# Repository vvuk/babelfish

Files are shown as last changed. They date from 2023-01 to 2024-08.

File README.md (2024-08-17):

Babelfish
=========

_This is a work in progress._

Babelfish is a hardware device and associated software to allow using a USB keyboard and mouse on a variety of retro computers.

Planned or in progress emulations include:

* Apollo
  * DN[3-5]XXX, DN10000, HP9000 series 400 with Domain/OS.
  * DN300
* SGI (pre-PS2)
* Sun (pre-PS2)
* Mac ADB
* PS/2 ?

The Sun code is based on the (USB2Sun)[] project.

## Hardware

TBD.

## Building

TBD.

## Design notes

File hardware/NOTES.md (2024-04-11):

Babelfish
=========

# v0.3

Fixes from v0.2:
- CH_B_S0/S1 routed to GPIO12 and GPIO13
- exposed DB9 GPIO moved from GPIO13+14 to 14+15.
  - DB9 pin 4 became GPIO15, pin 5 became GPIO14

| GPIO # | Usage |
| ====== | ===== |
|  0 | TX_A |
|  1 | RX_A |
|  2 | CH_A_S0 - A channel output select |
|  3 | CH_A_S1 - A channel output select |
|  6 | LED_PWR |
|  8 | TX_B |
|  9 | RX_B |
| 10 | LED_P_OK |
| 11 | LED_AUX |
| 12 | CH_B_S0 |
| 13 | CH_B_S1 |
| 14 | GPIO14 |
| 15 | GPIO15 |
| 18 | USB2_D- |
| 19 | USB2_D+ |
| 20 | USB2_EN |
| 21 | USB2_FLG |
| 23 | STAT_5V0 |

# v0.2

TPMCP1703T-5002E/CB -- SOT-23-3 20V max input, 300mA max current. How will this play with 357mA current limit on TPS2113? And will this be enough to power USB and RP2040?
TPMCP1703T-3302E/CB - SOT-23-3 

DE9 connector. Female.

5   4   3   2   1
  9   8   7   6

1 - GND
2 - TX A
3 - TX B
4 - GPIO15
5 - GPIO14
6 - VCC_IN
7 - RX A
8 - RX B
9

# Legacy notes
## v01

debug connector:

3v3 SWCLK GND SWD

for power series, top pin is to feed lines

usb2
DP = GPIO19, pin 30
DM = GPIO18, pin 29

pin 1 - U0 TX  - GP0   A1
pin 2 - U0 RX - GP1   A2

pin 6 - U1 TX - GP4   A3
pin 7 - U1 RX - GP5   A4

U1 TX - GP8
U1 RX - GP9

U0 TX - GP12
U0 RX - GP13

U0 TX - GP16
U0 RX - GP17

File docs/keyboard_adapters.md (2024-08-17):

# Keyboard Adapters

Babelfish DE9 connector (Female):

```
5   4   3   2   1
  9   8   7   6

1 - GND
2 - TX A
3 - TX B
4 - GPIO14
5 - GPIO15
6 - VCC_5V (5V in, if available)
7 - RX A
8 - RX B
9 - 3v3 (out)
```

## Apollo

CPU end of _*cable*_ (yes, these are the actual DIN8 pin numbers):

```
              U          1 - +8.5 Vdc (see below)     Red wire
          6o    7o       2 - Data to CPU (TXD)        Yellow wire
                         3 - Logic ground             Green wire
        1o        3o     4 - RESET                    Orange wire
             8o          5 - Data to keyboard (RXD)   Grey wire
          4o    5o       6 - Not used
             2o          7 - Logic ground             Blue wire
                         8 - Not used
                    SHIELD - Chassis ground
```

| Babelfish DB9 | Apollo DIN8 |
| :--- | :--- |
| 1 (GND) | 3, 7 (Logic ground) (white/3) |  
| 2 (TX A) | 2 (Data to CPU) (light brown/light orange) |
| 7 (RX A) | 5 (Data to keyboard) (yellow) |
| | 4 (RESET) (dark brown) |

## Apollo DN300

RJ45 connector:

```
      | 1 2 3 4 5 6 7 8 |      1 - NC
      |                 |      2 - NC
      +---+         +---+      3 - +3V3 (maybe?)
          +-+     +-+          4 - Data to CPU (TXD)
            +-----+            5 - 1.2kHz clock
                               6 - Logic ground
                               7 - NC
                               8 - NC
```

| Babelfish DB9 | Apollo DN300 RJ45 |
| :--- | :--- |
| 1 (GND) | 6 (Logic ground) |
| 2 (TX A) | 4 (Data to CPU) |

## ADB

Looking at male cable end:

```
      3  4
     1    2
       == 

1 - yellow - DATA
2 - green - power sw
3 - red - VCC 5V
4 - black  - GND
```

| Babelfish DB9 | ADB Mini-DIN 4 |
| :--- | :--- |
| 1 (GND) | 4 (GND) (black) |
| 2 (TX A) | 1 (ADB) (yellow) |
| 3 (TX B) | 2 (Power SW) (green) |
| 6 (VCC_5V) | 3 (5V) (red) |

Cable I have has black, yellow, red, green. 

## Sun (pre-PS/2)

(todo)

## SGI (pre-PS/2)

(todo)

## NeXT

MCLK   7   yellow
MOUT   2   orange
MIN    3   green
-12v  nc
NC    nc
GND    1   brown

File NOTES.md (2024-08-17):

NeXT

0xc5 0xde 0x00 0x00 0x00 -- I think this is an address set? Should be 0xef?
0xc5 0x00 0x06 0x00 0x00 -- Hmm this should be 0x3, this is wrong?

many 0xff = reset

seen on MOUT:
0xc5 0x00 0x03 0x00 0x00 -- 0xC5 -- kbhi = 0x00, kblo = 0x03  -- turn both LEDs on
longish delay
0xc5 0x00 0x00 0x00 0x00  -- turn both LEDs off
delay
0xc6 0x01 0xff 0xff 0xf6 -- 0xc6 is supposed to be an asic-to-computer response?

kbhi = R2 R1 R0 RW x x x A0 ; 0x00 = register 0, write 0, data 0x3

Host 0xc5 0xf0 xx xx xx -- read keyb version, or 0xf1 read mouse version
Reply 0xc6 paddr asicrev devver devid

We should reply
  0xc6
  0b00010000 -- master keyboard, asic originated event
  0x00 -- old asic version
  msb -- metakey code
  lsb -- keycode

-- rom Monitor -- right command key + ~ key on numeric keypad

From Previous:

-> C5 EF000000  -> set addr to 0; should ignore
<- C6 70000000  -> is this some kind of ack?

-> C5 00030000  -> turn on left/right LEDs
<- C6 70000000

-> C5 00000000  -> turn off LEDs
<- C6 70000000

-> C6 01fffff6 -> ... uhh
-> 00
"Command read 0x00"

-> C6 01fffff6 -> Set keyboard mouse poll -- mask & speed, ahh
-> 00

Apollo

Keyboard log after booting domain_os:

```
[   50866] IN: 00 (bytes: 0 cmd: 00000000 reading_cmd: 0)
Unknown keyboard command start byte [not-in-cmd]: 00
[   57317] IN: ff (bytes: 0 cmd: 00000000 reading_cmd: 0)
[   57319] IN: 00 (bytes: 0 cmd: 00000000 reading_cmd: 1)
Keyboard command: 00000000
Got 00000000 command with 0 bytes
[   63278] IN: ff (bytes: 0 cmd: 00000000 reading_cmd: 0)
[   65254] IN: 00 (bytes: 0 cmd: 00000000 reading_cmd: 1)
Keyboard command: 00000000
Got 00000000 command with 0 bytes
[   65262] IN: ff (bytes: 0 cmd: 00000000 reading_cmd: 0)
[   65267] IN: 12 (bytes: 0 cmd: 00000000 reading_cmd: 1)
[   65272] IN: 21 (bytes: 1 cmd: 00000012 reading_cmd: 1)
```

i53 / 15 / 1637

ST15150N: 78 / 21 / 5119

after booting domain_os; responses resulted in junk answers to "do yo uawnt to run domain_os with current calendar" prompt:

(apollo:0) recv ff
(apollo:0) recv 00
(apollo:0)  command 00000000 (1 bytes)
(apollo:0) Setting keyboard mode to 0
(apollo:0) xmit ff
(apollo:0) xmit 00
(apollo:0)  command handled
(apollo:0) recv ff
(apollo:0) recv 00
(apollo:0)  command 00000000 (1 bytes)
(apollo:0) Setting keyboard mode to 0
(apollo:0) xmit ff
(apollo:0) xmit 00
(apollo:0)  command handled
(apollo:0) recv ff
(apollo:0) recv 00
(apollo:0)  command 00000000 (1 bytes)
(apollo:0) Setting keyboard mode to 0
(apollo:0) xmit ff
(apollo:0) xmit 00
(apollo:0)  command handled
(apollo:0) recv ff
(apollo:0) recv 12
(apollo:0)  command 00000012 (1 bytes)
(apollo:0) recv 21
[started sending here]

booting the os --

(apollo:0) recv ff
(apollo:0) recv 00
(apollo:0)  command 00000000 (1 bytes)
(apollo:0) Setting keyboard mode to 0
(apollo:0) xmit ff
(apollo:0) xmit 00
(apollo:0)  command handled
(apollo:0) recv ff
(apollo:0) recv 01
(apollo:0)  command 00000001 (1 bytes)
(apollo:0) Setting keyboard mode to 1
(apollo:0) xmit ff
(apollo:0) xmit 01
(apollo:0)  command handled
(apollo:0) recv ff
(apollo:0) recv 12
(apollo:0)  command 00000012 (1 bytes)
(apollo:0) recv 21
(apollo:0)  command 00001221 (2 bytes)
(apollo:0) keyboard ident request
'D-03863-MSxmit str '3-@
(apollo:0)  command handled
(apollo:0) recv 00
(apollo:0) recv 00
(apollo:0) recv 00
(apollo:0) recv 00
(apollo:0) recv 00
(apollo:0) recv 00
(apollo:0) recv 00
(apollo:0) recv 00
(apollo:0) recv 00
(apollo:0) recv 00
(apollo:0) recv 00
(apollo:0) recv 00
(apollo:0) recv 00
(apollo:0) recv 00
(apollo:0) recv 00

resulted in uqyqr\qru]puqk\ in the login prompt

upon using the mouse, the keyboard keys seem to be sending mouse input?

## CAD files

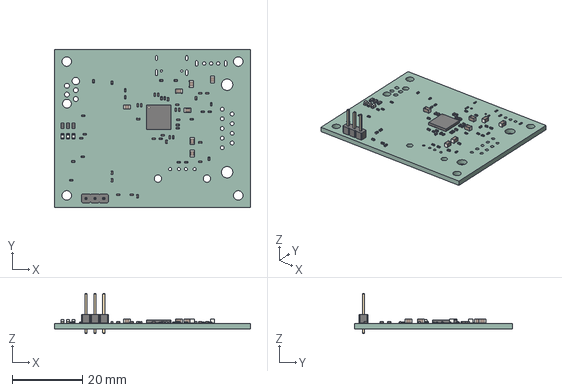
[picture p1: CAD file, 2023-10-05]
hardware/v2/babelfish.step
56.0 x 45.2 x 11.5 mm
babelfish PCB

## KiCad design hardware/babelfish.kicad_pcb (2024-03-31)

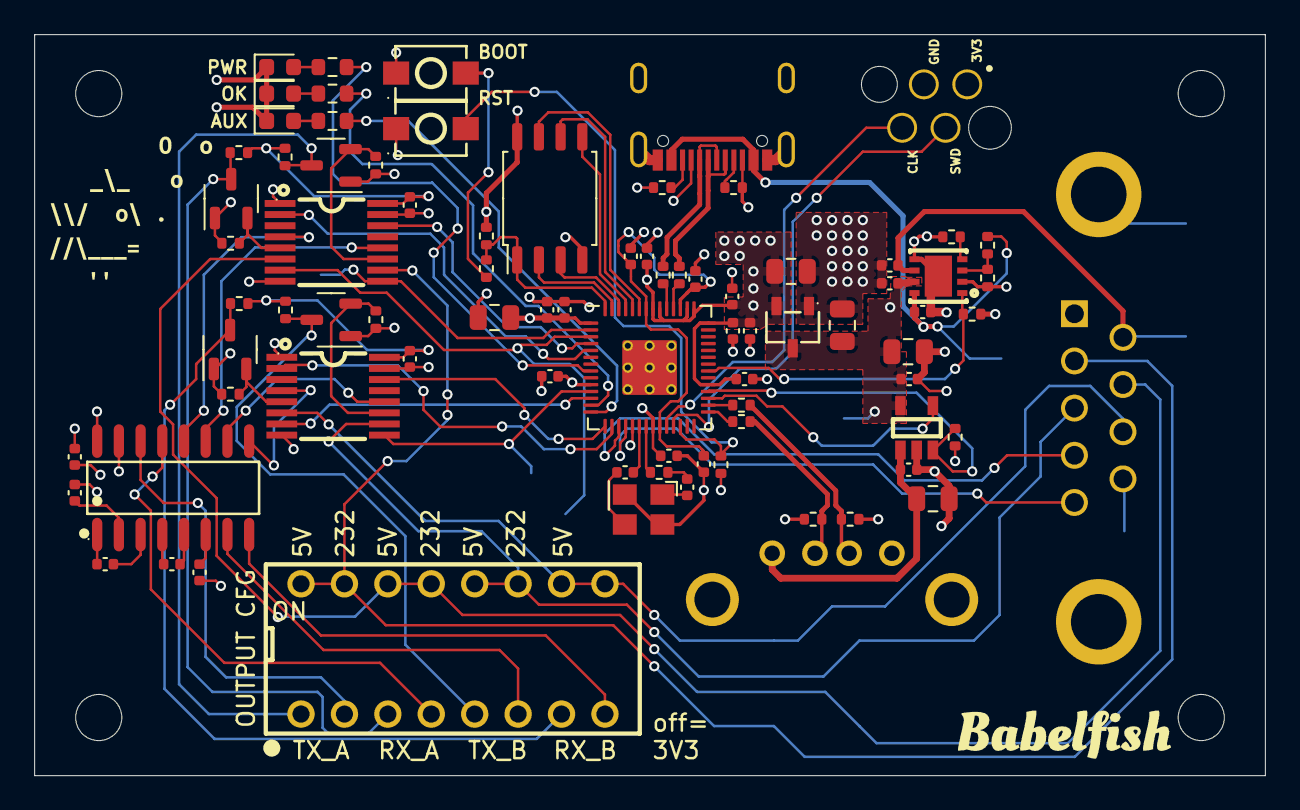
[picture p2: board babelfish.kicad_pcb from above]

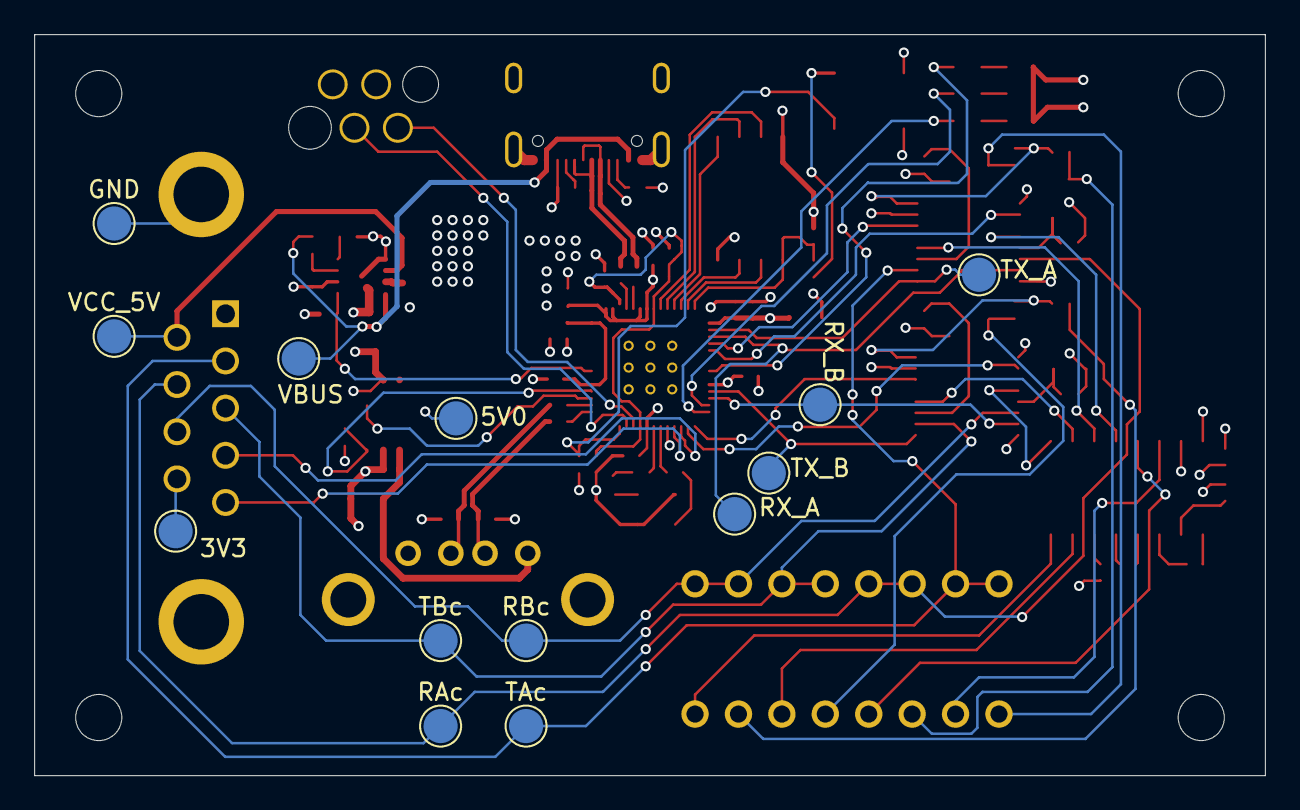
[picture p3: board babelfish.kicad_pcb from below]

Board: 4 copper layers, 72.0 x 43.4 mm, 101 parts (13 on the bottom side), 79 nets.

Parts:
3V3, 5V0: TestPoint; TestPoint_Pad_D2.0mm
C1, C2, C4, C5, C6, C7, C8, C9, C10, C15, C16, C18, C23, C24, C25, C26, C27, C28, C30, C36, C37: 100n; C_0402_1005Metric
C3, C21, C22, C29, C31: 10u; C_0805_2012Metric
C11, C12: 30p; C_0402_1005Metric
C13, C14, C17: 1u; C_0402_1005Metric
D1, D2, D3: Red; LED_0603_1608Metric
DIP1: KF1001-08P-R0-GL-DFT-01B; SW-TH_16P-L21.9-W9.9-P2.54-LS7.6
GND: TestPoint; TestPoint_Pad_D2.0mm
H1, H2, H3, H4: MountingHole; MountingHole_2.7mm_M2.5
J2: SWD; 490107670412
J3: DE9 Female; DSUB-TH_DMR-9S
J4: USB_A; USB-A-TH__USB-AF-90
Q1: BSS138; SOT-23-3
Q2, Q3, Q4: SOT-23-3
R1, R11: 1k; R_0402_1005Metric
R2, R14, R18, R19, R20, R21, R22, R23, R24, R25, R28: 10k; R_0402_1005Metric
R3, R4: 27; R_0402_1005Metric
R5, R10: 5.1K; R_0402_1005Metric
R6: 10k2; R_0402_1005Metric
R7: DNF; R_0402_1005Metric
R8: 2k05; R_0402_1005Metric
R9: 1k4; R_0402_1005Metric
R12, R13: 22; R_0402_1005Metric
R15, R16, R17: 1k; R_0603_1608Metric
R26, R27: 15k; R_0402_1005Metric
RAc: TestPoint; TestPoint_Pad_D2.0mm
RBc: TestPoint; TestPoint_Pad_D2.0mm
RX_A: TestPoint; TestPoint_Pad_D2.0mm
RX_B: TestPoint; TestPoint_Pad_D2.0mm
SW1, SW2: TS342A2P-WZ; SW-SMD_L4.0-W2.9-LS5.0
TAc: TestPoint; TestPoint_Pad_D2.0mm
TBc: TestPoint; TestPoint_Pad_D2.0mm
TX_A: TestPoint; TestPoint_Pad_D2.0mm
TX_B: TestPoint; TestPoint_Pad_D2.0mm
U1: RP2040; RP2040-QFN-56
U2: TPS2113ADRBR; SON-8_L3.0-W3.0-P0.65-LS3.0-BL-EP
U3: GT-USB-7010ASV; USB-C-SMD_G-SWITCH_GT-USB-7010ASV
U4: W25Q128JVS; SOIC-8_5.23x5.23mm_P1.27mm
U6: TPMCP1703T-3302E_CB; SOT-23-3_L2.9-W1.6-P1.90-LS2.8-BR
U7, U8: SN74CBT3253CPWR; TSSOP-16_L5.0-W4.4-P0.65-LS6.4-TL
U11: MAX3232IDR; SOIC-16_L9.9-W3.9-P1.27-LS6.0-BL
U12: AP2191WG-7; SOT-25-5_L2.9-W1.6-P0.95-LS2.8-BL
VBUS: TestPoint; TestPoint_Pad_D2.0mm
VCC_5V: TestPoint; TestPoint_Pad_D2.0mm
X1: X322512MSB4SI; OSC-SMD_4P-L3.2-W2.5-BL
kibuzzard-644F39EB: G***; kibuzzard-644F39EB
kibuzzard-644F3679: G***; kibuzzard-644F3679

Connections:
+1V1: C1.1, C2.1, C13.1, U1.23 (DVDD), U1.45 (VREG_VOUT), U1.50 (DVDD)
+3V3: 3V3.1, C3.1, C4.1, C5.1, C6.1, C7.1, C8.1, C9.1, C10.1, C14.1, C16.1, C22.1, C25.1, J2.1, J3.9, Q1.1 (G), Q2.1 (G), Q3.1 (G), Q4.1 (G), R2.2, R7.1, R14.2, R18.1, R20.1, R22.1, R24.1, R28.2, U1.1 (IOVDD), U1.10 (IOVDD), U1.22 (IOVDD), U1.33 (IOVDD), U1.42 (IOVDD), U1.43 (ADC_AVDD), U1.44 (VREG_IN), U1.48 (USB_VDD), U1.49 (IOVDD), U4.8 (VCC), U6.2 (VOUT), U11.16 (VCC)
/5V0: 5V0.1, C17.1, C21.1, C30.1, C31.1, C36.2, C37.2, R19.1, R21.1, R23.1, R25.1, U2.7 (OUT), U6.3 (VIN), U7.16 (VCC), U8.16 (VCC), U12.5 (IN)
/CH_A_S0: U1.4 (GPIO2), U7.14 (S0)
/CH_A_S1: U1.5 (GPIO3), U7.2 (S1)
/CH_B_S0: U1.15 (GPIO12), U8.14 (S0)
/CH_B_S1: U1.16 (GPIO13), U8.2 (S1)
/GPIO14: J3.4, U1.17 (GPIO14)
/GPIO15: J3.5, U1.18 (GPIO15)
/GPIO18: R12.2, U1.29 (GPIO18)
/GPIO19: R13.2, U1.30 (GPIO19)
/LED_AUX: R17.1, U1.14 (GPIO11)
/LED_PWR: R15.1, U1.8 (GPIO6)
/LED_P_OK: R16.1, U1.13 (GPIO10)
/OSC1: C11.1, X1.1 (OSC1)
/OSC1R: C11.2, R1.1
/OSC2: C12.1, X1.3 (OSC2)
/PWR_VSNS: R6.2, R8.1, U2.3 (VSNS)
/QSPI_SCLK: U1.52 (QSPI_SCLK), U4.6 (CLK)
/QSPI_SD0: U1.53 (QSPI_SD0), U4.5 (DI(IO0))
/QSPI_SD1: U1.55 (QSPI_SD1), U4.2 (DO(IO1))
/QSPI_SD2: U1.54 (QSPI_SD2), U4.3 (IO2)
/QSPI_SD3: U1.51 (QSPI_SD3), U4.7 (IO3)
/QSPI_SS: R7.2, R11.1, U1.56 (QSPI_SS), U4.1 (~CS)
/RUN: R14.1, SW2.2, U1.26 (RUN)
/RX_A: RX_A.1, U1.3 (GPIO1), U7.7 (1A)
/RX_A_CONN: DIP1.13 (PIN13), DIP1.14 (PIN14), J3.7, RAc.1, U7.6 (1B1)
/RX_A_MAX: U7.4 (1B3), U11.12 (ROUT1)
/RX_A_MAX_OUT: DIP1.4 (PIN4), U11.13 (RIN1)
/RX_A_SHIFTER: Q1.2 (S), R18.2, U7.5 (1B2)
/RX_A_SHIFTER_OUT: DIP1.3 (PIN3), Q1.3 (D), R19.2
/RX_B: RX_B.1, U1.12 (GPIO9), U8.7 (1A)
/RX_B_CONN: DIP1.9 (PIN9), DIP1.10 (PIN10), J3.8, RBc.1, U8.6 (1B1)
/RX_B_MAX: U8.4 (1B3), U11.9 (ROUT2)
/RX_B_MAX_OUT: DIP1.8 (PIN8), U11.8 (RIN2)
/RX_B_SHIFTER: Q4.2 (S), R24.2, U8.5 (1B2)
/RX_B_SHIFTER_OUT: DIP1.7 (PIN7), Q4.3 (D), R25.2
/STAT_5V0: R2.1, U1.35 (GPIO23), U2.1 (STAT)
/SWCLK: J2.4, U1.24 (SWCLK)
/SWD: J2.2, U1.25 (SWD)
/TX_A: TX_A.1, U1.2 (GPIO0), U7.9 (2A)
/TX_A_CONN: DIP1.15 (PIN15), DIP1.16 (PIN16), J3.2, TAc.1, U7.10 (2B1)
/TX_A_MAX: U7.12 (2B3), U11.11 (DIN1)
/TX_A_MAX_OUT: DIP1.2 (PIN2), U11.14 (DOUT1)
/TX_A_SHIFTER: Q2.2 (S), R20.2, U7.11 (2B2)
/TX_A_SHIFTER_OUT: DIP1.1 (PIN1), Q2.3 (D), R21.2
/TX_B: TX_B.1, U1.11 (GPIO8), U8.9 (2A)
/TX_B_CONN: DIP1.11 (PIN11), DIP1.12 (PIN12), J3.3, TBc.1, U8.10 (2B1)
/TX_B_MAX: U8.12 (2B3), U11.10 (DIN2)
/TX_B_MAX_OUT: DIP1.6 (PIN6), U11.7 (DOUT2)
/TX_B_SHIFTER: Q3.2 (S), R22.2, U8.11 (2B2)
/TX_B_SHIFTER_OUT: DIP1.5 (PIN5), Q3.3 (D), R23.2
/USB2_D+: J4.3 (D+), R13.1, R27.1
/USB2_D-: J4.2 (D-), R12.1, R26.1
/USB2_EN: U1.31 (GPIO20), U12.4 (EN)
/USB2_FLG: R28.1, U1.32 (GPIO21), U12.3 (FLG)
/USB_D+: R3.1, U3.A6 (DP1), U3.B6 (DP2)
/USB_D-: R4.1, U3.A7 (DN1), U3.B7 (DN2)
/USB_DN: R4.2, U1.46 (USB_DM)
/USB_DP: R3.2, U1.47 (USB_DP)
/VBUS_OUT: C28.1, C29.1, J4.1 (VBUS), U12.1 (OUT)
/VCC_5V: C18.1, J3.6, U2.6 (IN2), VCC_5V.1
/XIN: C12.2, U1.20 (XIN)
/XOUT: R1.2, U1.21 (XOUT)
/~USB_BOOT: R11.2, SW1.2
GND: C1.2, C2.2, C3.2, C4.2, C5.2, C6.2, C7.2, C8.2, C9.2, C10.2, C13.2, C14.2, C15.2, C16.2, C17.2, C18.2, C21.2, C22.2, C23.1, C25.2, C27.2, C28.2, C29.2, C30.2, C31.2, C36.1, C37.1, D1.1 (K), D2.1 (K), D3.1 (K), GND.1, J2.3, J3.1, J3.10 (PAD), J3.11 (PAD), J4.4 (GND), J4.5 (Shield), R5.2, R8.2, R9.2, R10.2, R26.2, R27.2, SW1.1, SW2.1, U1.19 (TESTEN), U1.57 (GND), U2.2 (EN#), U2.5 (GND), U2.9 (EP), U3.1 (SHELL), U3.2 (SHELL), U3.3 (SHELL), U3.4 (SHELL), U3.A1B12 (GND), U3.A8 (SBU1), U3.B1A12 (GND), U3.B8 (SBU2), U4.4 (GND), U6.1 (GND), U7.1 (1OE#), U7.8 (GND), U7.15 (2OE#), U8.1 (1OE#), U8.8 (GND), U8.15 (2OE#), U11.15 (GND), U12.2 (GND), X1.2 (GND), X1.4 (GND)
unnamed: D1.2 (A), R15.2
unnamed: D2.2 (A), R16.2
unnamed: D3.2 (A), R17.2
unnamed: R9.1, U2.4 (ILIM)
unnamed: R10.1, U3.A5 (CC1)
unnamed: R5.1, U3.B5 (CC2)
unnamed: C24.1, U11.1 (C1+)
unnamed: C24.2, U11.3 (C1-)
unnamed: C26.1, U11.4 (C2+)
unnamed: C26.2, U11.5 (C2-)
unnamed: C23.2, U11.2 (V+)
unnamed: C27.1, U11.6 (V-)
VBUS: C15.1, R6.1, U2.8 (IN1), U3.A4B9 (VBUS), U3.B4A9 (VBUS), VBUS.1

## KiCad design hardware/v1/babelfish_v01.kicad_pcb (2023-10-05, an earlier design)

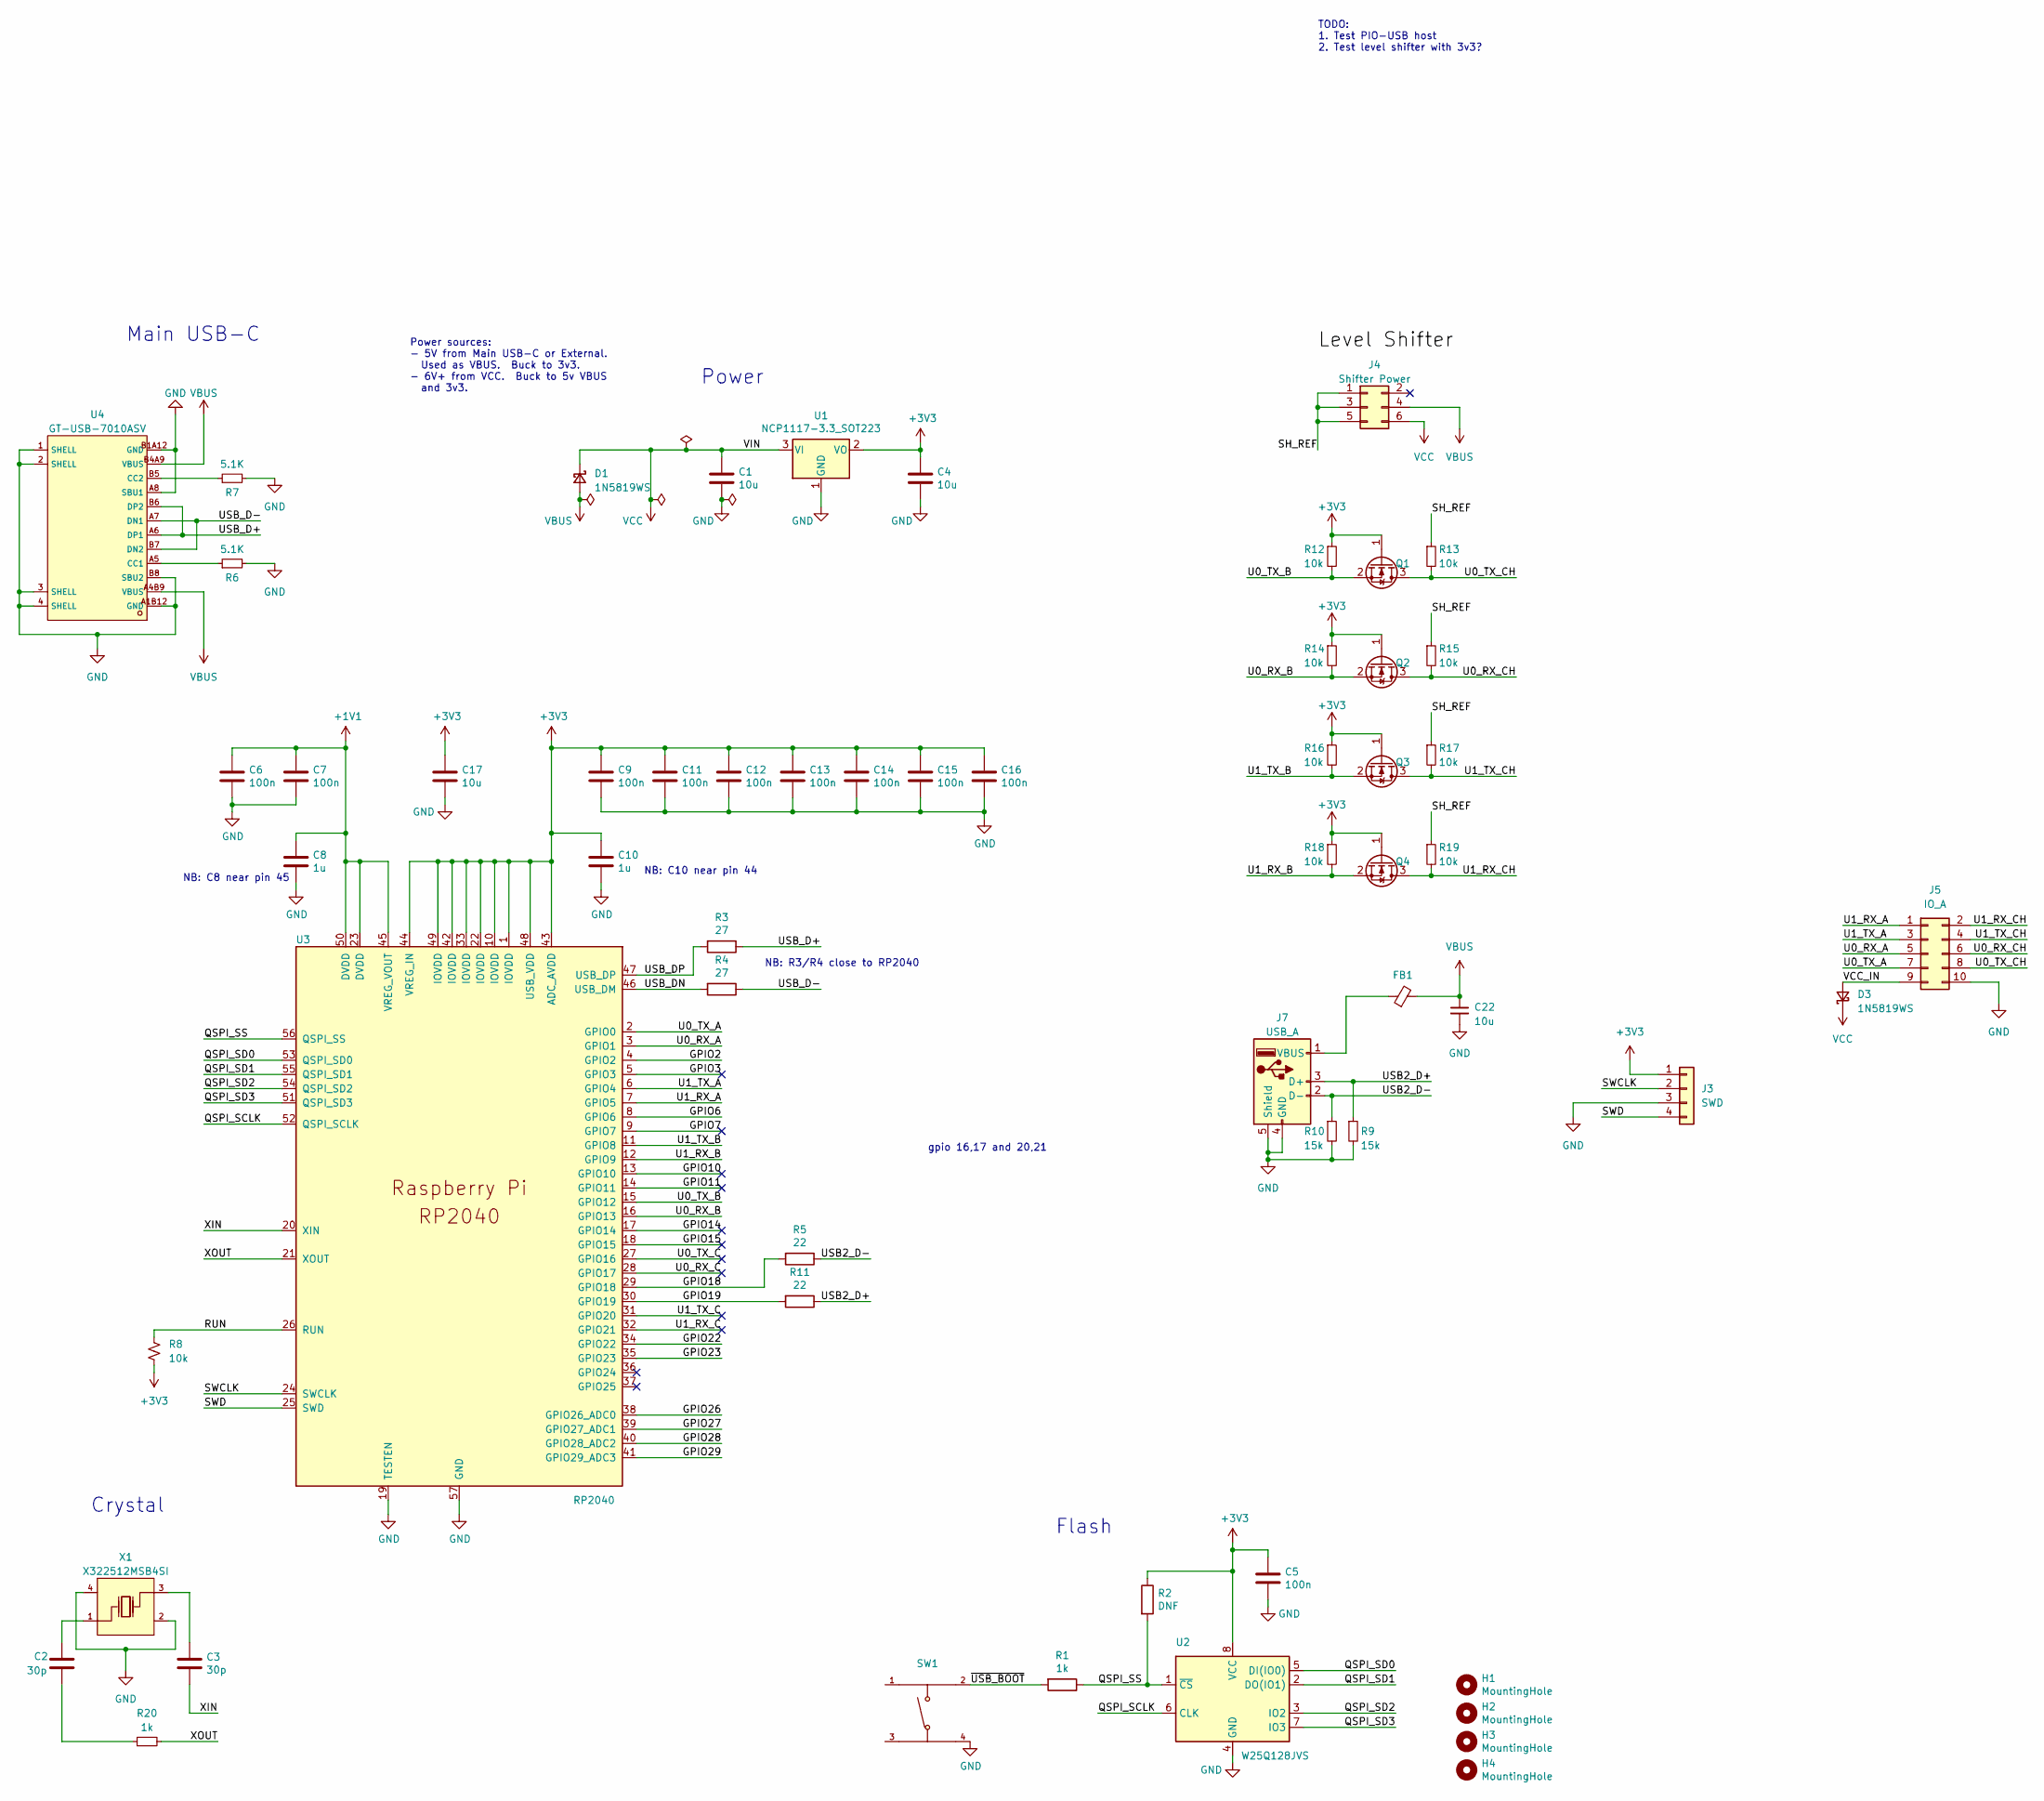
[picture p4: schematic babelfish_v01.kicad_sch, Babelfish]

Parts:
C1, C4, C17, C22: 10u; C_0805_2012Metric
C2, C3: 30p; C_0402_1005Metric
C5, C6, C7, C9, C11, C12, C13, C14, C15, C16: 100n; C_0402_1005Metric
C8, C10: 1u; C_0402_1005Metric
D1, D3: 1N5819WS; D_SOD-323
FB1: FerriteBead_Small; L_0805_2012Metric
H1, H2, H3, H4: MountingHole; MountingHole_2.7mm_M2.5
J3: SWD; PinHeader_1x04_P2.54mm_Vertical
J4: Shifter Power; PinHeader_2x03_P2.54mm_Vertical
J5: IO_A; PinHeader_2x05_P2.54mm_Horizontal
J7: USB_A; USB-A-TH__USB-AF-90; Part 902-131A1011D10100; LCSC C2345
Q1: BSS138; SOT-23-3
Q2, Q3, Q4: SOT-23-3
R1, R20: 1k; R_0402_1005Metric
R2: DNF; R_0402_1005Metric
R3, R4: 27; R_0402_1005Metric
R5, R11: 22; R_0402_1005Metric
R6, R7: 5.1K; R_0402_1005Metric
R8, R12, R13, R14, R15, R16, R17, R18, R19: 10k; R_0402_1005Metric
R9, R10: 15k; R_0402_1005Metric
SW1: K2-1156SP-D5SW-05; SW-SMD_4P-L6.3-W6.2-P4.00-LS9.4-TL; LCSC C128948
U1: NCP1117-3.3_SOT223; SOT-223-3_TabPin2
U2: W25Q128JVS; SOIC-8_5.23x5.23mm_P1.27mm
U3: RP2040; RP2040-QFN-56
U4: GT-USB-7010ASV; USB-C-SMD_G-SWITCH_GT-USB-7010ASV; LCSC C2988369
X1: X322512MSB4SI; OSC-SMD_4P-L3.2-W2.5-BL; LCSC C9002

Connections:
+1V1: C6.1, C7.1, C8.1, U3.23 (DVDD), U3.45 (VREG_VOUT), U3.50 (DVDD)
+3V3: C4.1, C5.1, C9.1, C10.1, C11.1, C12.1, C13.1, C14.1, C15.1, C16.1, C17.1, J3.1, Q1.1 (G), Q2.1 (G), Q3.1 (G), Q4.1 (G), R2.1, R8.2, R12.1, R14.1, R16.1, R18.1, U1.2 (VO), U2.8 (VCC), U3.1 (IOVDD), U3.10 (IOVDD), U3.22 (IOVDD), U3.33 (IOVDD), U3.42 (IOVDD), U3.43 (ADC_AVDD), U3.44 (VREG_IN), U3.48 (USB_VDD), U3.49 (IOVDD)
/GPIO2: U3.4 (GPIO2)
/GPIO3: U3.5 (GPIO3)
/GPIO6: U3.8 (GPIO6)
/GPIO7: U3.9 (GPIO7)
/GPIO10: U3.13 (GPIO10)
/GPIO11: U3.14 (GPIO11)
/GPIO14: U3.17 (GPIO14)
/GPIO15: U3.18 (GPIO15)
/GPIO18: R5.2, U3.29 (GPIO18)
/GPIO19: R11.2, U3.30 (GPIO19)
/GPIO22: U3.34 (GPIO22)
/GPIO23: U3.35 (GPIO23)
/GPIO26: U3.38 (GPIO26_ADC0)
/GPIO27: U3.39 (GPIO27_ADC1)
/GPIO28: U3.40 (GPIO28_ADC2)
/GPIO29: U3.41 (GPIO29_ADC3)
/QSPI_SCLK: U2.6 (CLK), U3.52 (QSPI_SCLK)
/QSPI_SD0: U2.5 (DI(IO0)), U3.53 (QSPI_SD0)
/QSPI_SD1: U2.2 (DO(IO1)), U3.55 (QSPI_SD1)
/QSPI_SD2: U2.3 (IO2), U3.54 (QSPI_SD2)
/QSPI_SD3: U2.7 (IO3), U3.51 (QSPI_SD3)
/QSPI_SS: R1.1, R2.2, U2.1 (~CS), U3.56 (QSPI_SS)
/RUN: R8.1, U3.26 (RUN)
/SH_REF: J4.1, J4.3, J4.5, R13.1, R15.1, R17.1, R19.1
/SWCLK: J3.2, U3.24 (SWCLK)
/SWD: J3.4, U3.25 (SWD)
/U0_RX_A: J5.5, U3.3 (GPIO1)
/U0_RX_B: Q2.2 (S), R14.2, U3.16 (GPIO13)
/U0_RX_C: U3.28 (GPIO17)
/U0_RX_CH: J5.6, Q2.3 (D), R15.2
/U0_TX_A: J5.7, U3.2 (GPIO0)
/U0_TX_B: Q1.2 (S), R12.2, U3.15 (GPIO12)
/U0_TX_C: U3.27 (GPIO16)
/U0_TX_CH: J5.8, Q1.3 (D), R13.2
/U1_RX_A: J5.1, U3.7 (GPIO5)
/U1_RX_B: Q4.2 (S), R18.2, U3.12 (GPIO9)
/U1_RX_C: U3.32 (GPIO21)
/U1_RX_CH: J5.2, Q4.3 (D), R19.2
/U1_TX_A: J5.3, U3.6 (GPIO4)
/U1_TX_B: Q3.2 (S), R16.2, U3.11 (GPIO8)
/U1_TX_C: U3.31 (GPIO20)
/U1_TX_CH: J5.4, Q3.3 (D), R17.2
/USB2_D+: J7.3 (D+), R9.1, R11.1
/USB2_D-: J7.2 (D-), R5.1, R10.1
/USB_D+: R3.1, U4.A6 (DP1), U4.B6 (DP2)
/USB_D-: R4.1, U4.A7 (DN1), U4.B7 (DN2)
/USB_DN: R4.2, U3.46 (USB_DM)
/USB_DP: R3.2, U3.47 (USB_DP)
/VCC_IN: D3.2 (A), J5.9
/XIN: C3.2, U3.20 (XIN)
/XOUT: R20.2, U3.21 (XOUT)
/~USB_BOOT: R1.2, SW1.2
GND: C1.2, C4.2, C5.2, C6.2, C7.2, C8.2, C9.2, C10.2, C11.2, C12.2, C13.2, C14.2, C15.2, C16.2, C17.2, C22.2, J3.3, J5.10, J7.4 (GND), J7.5 (Shield), R6.2, R7.2, R9.2, R10.2, SW1.4, U1.1 (GND), U2.4 (GND), U3.19 (TESTEN), U3.57 (GND), U4.1 (SHELL), U4.2 (SHELL), U4.3 (SHELL), U4.4 (SHELL), U4.A1B12 (GND), U4.A8 (SBU1), U4.B1A12 (GND), U4.B8 (SBU2), X1.2 (GND), X1.4 (GND)
unnamed: C2.2, R20.1
unnamed: FB1.1, J7.1 (VBUS)
unnamed: R6.1, U4.A5 (CC1)
unnamed: R7.1, U4.B5 (CC2)
unnamed: C2.1, X1.1 (OSC1)
unnamed: C3.1, X1.3 (OSC2)
VBUS: C22.1, D1.2 (A), FB1.2, J4.4, U4.A4B9 (VBUS), U4.B4A9 (VBUS)
VCC: C1.1, D1.1 (K), D3.1 (K), J4.6, U1.3 (VI)

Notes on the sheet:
gpio 16,17 and 20,21
Crystal
NB: R3/R4 close to RP2040
NB: C8 near pin 45
Power sources: - 5V from Main USB-C or External. Used as VBUS. Buck to 3v3. - 6V+ from VCC. Buck to 5v VBUS and 3v3.
Flash
TODO: 1. Test PIO-USB host 2. Test level shifter with 3v3?
Main USB-C
Power
NB: C10 near pin 44

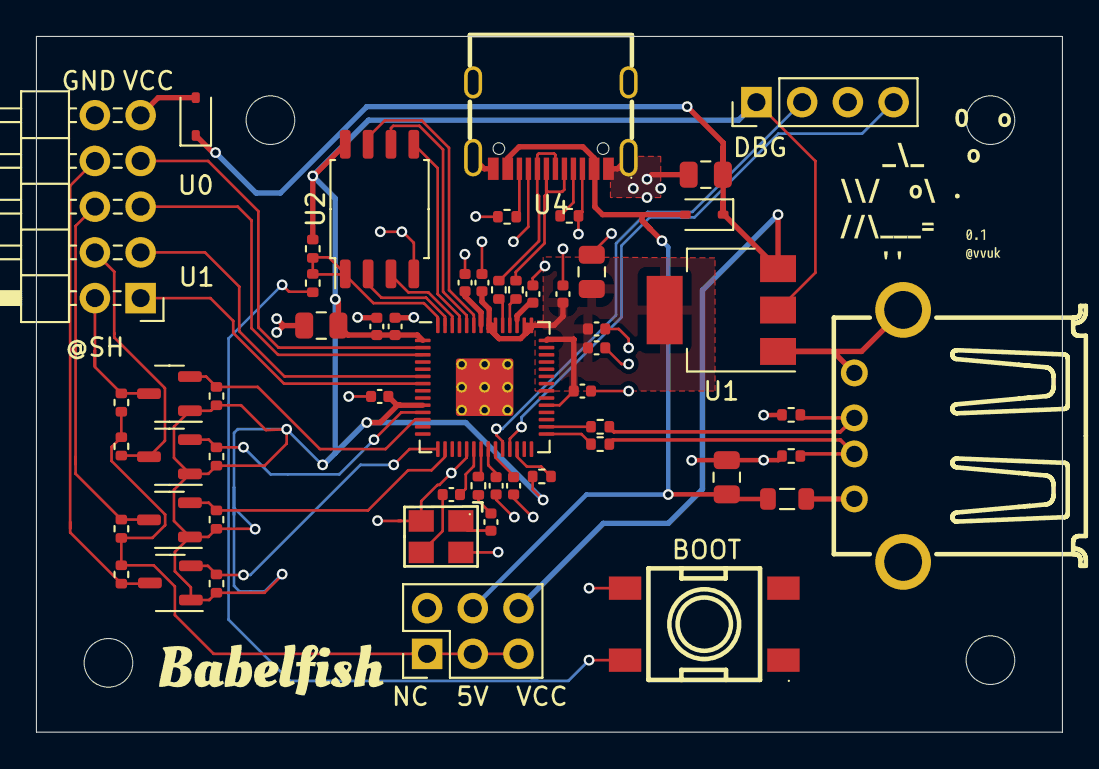
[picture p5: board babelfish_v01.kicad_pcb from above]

Board: 4 copper layers, 57.0 x 38.7 mm, 62 parts (0 on the bottom side), 45 nets.

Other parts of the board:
kibuzzard-644F3A2B: G***; kibuzzard-644F3A2B
kibuzzard-644F39EB: G***; kibuzzard-644F39EB
kibuzzard-644F3679: G***; kibuzzard-644F3679

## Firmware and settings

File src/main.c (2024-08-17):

#include <glob.h>
#include <sys/cdefs.h>
/*
 * Babelfish
 * Copyright (C) 2023 Vladimir Vukicevic
 *
 * Multihost USB keyboard/mouse adapter
 * 
 * Originally based on USB2Sun by Joakim L. Gilje
 * Originally based on TinyUSB Host examples
 */

#include <pico/stdlib.h>
#include <pico/multicore.h>
#include <tusb.h>
#include <pio_usb.h>
#include "stdio_nusb/stdio_usb.h"

#define DEBUG_VERBOSE 0
#define DEBUG_TAG "main"

#include "babelfish.h"

// Whether to run USB host on core1
#define USB_ON_CORE1 1

HOST_PROTOTYPES(sun);
HOST_PROTOTYPES(adb);
HOST_PROTOTYPES(apollo);
HOST_PROTOTYPES(apollo_dn300);
HOST_PROTOTYPES(next);
HOST_PROTOTYPES(test_3v3);

HostDevice hosts[] = {
  HOST_ENTRY(sun, "Sun emulation. Ch A RX/TX for keyboard, Ch B TX for mouse. Shifter setting 5V."),
  HOST_ENTRY(adb, "ADB emulation. Ch A RX bidirectional. Shifter setting 5V."),
  HOST_ENTRY(apollo, "Apollo emulation. Ch A RX/TX for keyboard and mouse. Shifter setting 5V."),
  HOST_ENTRY(apollo_dn300, "Apollo DN300 emulation. Ch A RX/TX for keyboard and mouse. Shifter setting 5V."),
  HOST_ENTRY(next, "NeXT emulation. Ch A used for MOUT/CLK, Ch B used for MIN. Shifter setting 5V for A TX+RX, 3v3 for B TX."),
  HOST_ENTRY(test_3v3, "3v3 TTL test. Transmits A on Ch A TX and B on Ch B TX every 0.5s, 1200 baud 8n1."),
  { 0 }
};

ChannelConfig channels[NUM_CHANNELS] = {
  {
    .channel_num = 0,
    .uart_num = 0,
    .tx_gpio = TX_A_GPIO,
    .rx_gpio = RX_A_GPIO,
    .mux_s0_gpio = CH_A_S0_GPIO,
    .mux_s1_gpio = CH_A_S1_GPIO,
  },
  {
    .channel_num = 1,
    .uart_num = 1,
    .tx_gpio = TX_B_GPIO,
    .rx_gpio = RX_B_GPIO,
    .mux_s0_gpio = CH_B_S0_GPIO,
    .mux_s1_gpio = CH_B_S1_GPIO,
  }
};

// TODO read from flash
int g_current_host_index = 2;

HostDevice *host = NULL;
KeyboardEvent kbd_event_queue[MAX_QUEUED_EVENTS];
MouseEvent mouse_event_queue[MAX_QUEUED_EVENTS];
uint8_t kbd_event_queue_count = 0;
uint8_t mouse_event_queue_count = 0;
mutex_t event_queue_mutex;

uint8_t const ascii_to_hid[128][2] = { HID_ASCII_TO_KEYCODE };
uint8_t const hid_to_ascii[128][2] = { HID_KEYCODE_TO_ASCII };

void usb_host_setup(void);
void core1_main(void);

_Noreturn void mainloop(void);
void channel_init(void);
void led_init(void);
void usb_aux_init(void);
bool cmd_process_event(KeyboardEvent ev);

int main(void)
{
  // need 120MHz for USB
  set_sys_clock_khz(120000, true);

  led_init();

  tud_init(0);

  stdio_nusb_init();

  for (int i = 0; i < 10 && !stdio_nusb_connected(); i++) {
    sleep_ms(100);
  }

  sleep_ms(100);

  DEBUG_INIT();

  DBG("==== B A B E L F I S H ====\n");

  usb_aux_init();

  DBG("Enabled AUX USB\n");

  sleep_ms(100);

  channel_init();

  mutex_init(&event_queue_mutex);

  // Initialize Core 1, and put PIO-USB on it with TinyUSB
  multicore_reset_core1();
  multicore_launch_core1(core1_main);

  host = &hosts[g_current_host_index];

  DBG("Selecting host '%s'\n", host->name);
  DBG("%s\n", host->notes);

  // TODO: read hostid from storage
  host->init();

  mainloop();

  return 0;
}

_Noreturn void mainloop(void)
{
  KeyboardEvent kbd_events[MAX_QUEUED_EVENTS];
  MouseEvent mouse_events[MAX_QUEUED_EVENTS];
  uint kbd_event_count = 0;
  uint mouse_event_count = 0;

  while (true) {
    DEBUG_TASK();

    get_queued_kbd_events(kbd_events, &kbd_event_count);
    get_queued_mouse_events(mouse_events, &mouse_event_count);

    for (uint i = 0; i < kbd_event_count; i++) {
      DBG_V("xmit key %s: [%d] 0x%04x\n", kbd_events[i].down ? "DOWN" : "UP", kbd_events[i].page, kbd_events[i].keycode);
      // if cmd_process_event took the event
      if (cmd_process_event(kbd_events[i]))
        continue;
      host->kbd_event(kbd_events[i]);
    }

    for (uint i = 0; i < mouse_event_count; i++) {
      host->mouse_event(mouse_events[i]);
    }

    host->update();

    gpio_put(LED_P_OK_GPIO, !gpio_get(USB_5V_STAT_GPIO));
    //gpio_put(LED_AUX_GPIO, tud_cdc_connected());
  }
}

void usb_host_setup()
{
  pio_usb_configuration_t pio_cfg = PIO_USB_DEFAULT_CONFIG;
  pio_cfg.pinout = PIO_USB_PINOUT_DMDP;
  pio_cfg.pin_dp = USB_AUX_DP_GPIO;

  tuh_configure(1, TUH_CFGID_RPI_PIO_USB_CONFIGURATION, &pio_cfg);

  tuh_init(1);
}

//
// Core 1 -- secondary USB port
//
void core1_main(void)
{
  sleep_ms(10);

  usb_host_setup();

  while (true) {
    tuh_task(); // tinyusb host task
  }
}

void enqueue_kbd_event(const KeyboardEvent* event)
{
  //DBG_VV("Enqueued key %s: [%d] 0x%04x\n", event->down ? "DOWN" : "UP", event->page, event->keycode);
  mutex_enter_blocking(&event_queue_mutex);
  if (kbd_event_queue_count < MAX_QUEUED_EVENTS) {
    kbd_event_queue[kbd_event_queue_count++] = *event;
  }
  mutex_exit(&event_queue_mutex);
}

void enqueue_mouse_event(const MouseEvent* event)
{
  //DBG("Enqueued mouse\n");
  mutex_enter_blocking(&event_queue_mutex);
  if (mouse_event_queue_count < MAX_QUEUED_EVENTS) {
    mouse_event_queue[mouse_event_queue_count++] = *event;
  }
  mutex_exit(&event_queue_mutex);
}

void get_queued_kbd_events(KeyboardEvent* events, uint* count)
{
  mutex_enter_blocking(&event_queue_mutex);
  *count = kbd_event_queue_count;
  memcpy(events, kbd_event_queue, sizeof(KeyboardEvent) * kbd_event_queue_count);
  kbd_event_queue_count = 0;
  mutex_exit(&event_queue_mutex);
}

void get_queued_mouse_events(MouseEvent* events, uint* count)
{
  mutex_enter_blocking(&event_queue_mutex);
  *count = mouse_event_queue_count;
  memcpy(events, mouse_event_queue, sizeof(MouseEvent) * mouse_event_queue_count);
  mouse_event_queue_count = 0;
  mutex_exit(&event_queue_mutex);
}

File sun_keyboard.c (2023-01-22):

#include <tusb.h>

#include <pico/stdlib.h>
#include <hardware/uart.h>
#include <hardware/irq.h>

#include "sun_keycodes.h"

#define UART_KBD_ID uart1
#define UART_KBD_IRQ UART1_IRQ
#define UART_KBD_TX_PIN 4
#define UART_KBD_RX_PIN 5

static void on_keyboard_rx();

void sun_keyboard_uart_init() {
  uart_init(UART_KBD_ID, 1200);
  gpio_set_function(UART_KBD_TX_PIN, GPIO_FUNC_UART);
  gpio_set_function(UART_KBD_RX_PIN, GPIO_FUNC_UART);
  uart_set_hw_flow(UART_KBD_ID, false, false);
  uart_set_format(UART_KBD_ID, 8, 1, UART_PARITY_NONE);
  irq_set_exclusive_handler(UART_KBD_IRQ, on_keyboard_rx);
  irq_set_enabled(UART_KBD_IRQ, true);
  uart_set_irq_enables(UART_KBD_ID, true, false);
  gpio_set_inover(UART_KBD_RX_PIN, GPIO_OVERRIDE_INVERT);
  gpio_set_outover(UART_KBD_TX_PIN, GPIO_OVERRIDE_INVERT);
}

// RX interrupt handler
void on_keyboard_rx() {
    while (uart_is_readable(UART_KBD_ID)) {
        // printf("System command: ");
        uint8_t ch = uart_getc(UART_KBD_ID);

        switch (ch) {
          case 0x01: // reset
            // printf("Reset\n");
            uart_putc_raw(UART_KBD_ID, 0xff);
            uart_putc_raw(UART_KBD_ID, 0x04);
            uart_putc_raw(UART_KBD_ID, 0x7f);
            break;
          case 0x02: // bell on
            // printf("Bell on\n");
            break;
          case 0x03: // bell off
            // printf("Bell off\n");
            break;
          case 0x0a: // click on
            // printf("Click on\n");
            break;
          case 0x0b: // click off
            // printf("Click off\n");
            break;
          case 0x0e: // led command
            // printf("Led\n");
            {
              uint8_t led = uart_getc(UART_KBD_ID);
            }
            break;
          case 0x0f: // layout command
            // printf("Layout\n");
            uart_putc_raw(UART_KBD_ID, 0xfe);
            uart_putc_raw(UART_KBD_ID, 0x00);
            break;
          default:
            // printf("Unknown system command: 0x%02x\n", ch);
            break;
        };
    }
}

static uint8_t hotkey_combo = KEYBOARD_MODIFIER_LEFTSHIFT | KEYBOARD_MODIFIER_LEFTCTRL;
static uint8_t active_key_list[128];
static uint8_t active_keys = 0;

void sun_kbd_report(hid_keyboard_report_t const *report) {
  uint8_t current_key_list[128];
  memset(current_key_list, 0, sizeof(current_key_list));

  if (report->modifier != 0) {
    current_key_list[usb2sun[HID_KEY_SHIFT_LEFT]]    = report->modifier & KEYBOARD_MODIFIER_LEFTSHIFT  ? 1 : 0;
    current_key_list[usb2sun[HID_KEY_CONTROL_LEFT]]  = report->modifier & KEYBOARD_MODIFIER_LEFTCTRL   ? 1 : 0;
    current_key_list[usb2sun[HID_KEY_ALT_LEFT]]      = report->modifier & KEYBOARD_MODIFIER_LEFTALT    ? 1 : 0;
    current_key_list[usb2sun[HID_KEY_GUI_LEFT]]      = report->modifier & KEYBOARD_MODIFIER_LEFTGUI    ? 1 : 0;
    current_key_list[usb2sun[HID_KEY_SHIFT_RIGHT]]   = report->modifier & KEYBOARD_MODIFIER_RIGHTSHIFT ? 1 : 0;
    current_key_list[usb2sun[HID_KEY_CONTROL_RIGHT]] = report->modifier & KEYBOARD_MODIFIER_RIGHTCTRL  ? 1 : 0;
    current_key_list[usb2sun[HID_KEY_ALT_RIGHT]]     = report->modifier & KEYBOARD_MODIFIER_RIGHTALT   ? 1 : 0;
    current_key_list[usb2sun[HID_KEY_GUI_RIGHT]]     = report->modifier & KEYBOARD_MODIFIER_RIGHTGUI   ? 1 : 0;
  }

  uint8_t i = 0;
  if (report->modifier == hotkey_combo) {
    current_key_list[usb2sun[HID_KEY_SHIFT_LEFT]] = 0;
    current_key_list[usb2sun[HID_KEY_CONTROL_LEFT]] = 0;
    switch (report->keycode[i]) {
      case HID_KEY_F1:
        current_key_list[SUN_KEY_STOP] = 1;
        break;
      case HID_KEY_F2:
        current_key_list[SUN_KEY_AGAIN] = 1;
        break;
      case HID_KEY_1:
        current_key_list[SUN_KEY_PROPS] = 1;
        break;
      case HID_KEY_2:
        current_key_list[SUN_KEY_UNDO] = 1;
        break;
      case HID_KEY_Q:
        current_key_list[SUN_KEY_FRONT] = 1;
        break;
      case HID_KEY_W:
        current_key_list[SUN_KEY_COPY] = 1;
        break;
      case HID_KEY_A:
        current_key_list[SUN_KEY_OPEN] = 1;
        break;
      case HID_KEY_S:
        current_key_list[SUN_KEY_PASTE] = 1;
        break;
      case HID_KEY_Z:
        current_key_list[SUN_KEY_FIND] = 1;
        break;
      case HID_KEY_X:
        current_key_list[SUN_KEY_CUT] = 1;
        break;
    }
    i++;
  }
  for (; i < 6; i++) {
    if (report->keycode[i]) {
      current_key_list[usb2sun[report->keycode[i]]] = 1;
    }
  }

  for (uint8_t i = 0; i < 128; i++) {
    if (active_key_list[i] && !current_key_list[i]) {
      uart_putc_raw(UART_KBD_ID, i | 0x80);
      active_key_list[i] = 0;
      active_keys--;
    }
    if (!active_key_list[i] && current_key_list[i]) {
      uart_putc_raw(UART_KBD_ID, i);
      active_key_list[i] = 1;
      active_keys++;
    }
  }

  if (active_keys == 0) {
    uart_putc_raw(UART_KBD_ID, 0x7f);
  }
}

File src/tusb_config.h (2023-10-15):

#ifndef _TUSB_CONFIG_H_
#define _TUSB_CONFIG_H_

#ifdef __cplusplus
 extern "C" {
#endif

//--------------------------------------------------------------------
// COMMON CONFIGURATION
//--------------------------------------------------------------------

#define CFG_TUSB_OS               OPT_OS_PICO

#define CFG_TUD_ENABLED     1
#define CFG_TUH_ENABLED     1
#define CFG_TUH_RPI_PIO_USB 1

// CFG_TUSB_DEBUG is defined by compiler in DEBUG build
// #define CFG_TUSB_DEBUG           0

/* USB DMA on some MCUs can only access a specific SRAM region with restriction on alignment.
 * Tinyusb use follows macros to declare transferring memory so that they can be put
 * into those specific section.
 * e.g
 * - CFG_TUSB_MEM SECTION : __attribute__ (( section(".usb_ram") ))
 * - CFG_TUSB_MEM_ALIGN   : __attribute__ ((aligned(4)))
 */
#ifndef CFG_TUSB_MEM_SECTION
#define CFG_TUSB_MEM_SECTION
#endif

#ifndef CFG_TUSB_MEM_ALIGN
#define CFG_TUSB_MEM_ALIGN          __attribute__ ((aligned(4)))
#endif

//--------------------------------------------------------------------
// DEVICE CONFIGURATION
//--------------------------------------------------------------------

#ifndef CFG_TUD_ENDPOINT0_SIZE
#define CFG_TUD_ENDPOINT0_SIZE    64
#endif

#define CFG_TUSB_RHPORT0_MODE (OPT_MODE_DEVICE)
//------------- CLASS -------------//
#define CFG_TUD_VENDOR           0
#define CFG_TUD_CDC              1

// CDC FIFO size of TX and RX
#define CFG_TUD_CDC_RX_BUFSIZE   256
#define CFG_TUD_CDC_TX_BUFSIZE   256

// CDC Endpoint transfer buffer size, more is faster
#define CFG_TUD_CDC_EP_BUFSIZE   64

//--------------------------------------------------------------------
// HOST CONFIGURATION
//--------------------------------------------------------------------

// Size of buffer to hold descriptors and other data used for enumeration
#define CFG_TUH_ENUMERATION_BUFSIZE 256

#define CFG_TUH_HUB                 1
// max device support (excluding hub device)
#define CFG_TUH_DEVICE_MAX          (CFG_TUH_HUB ? 4 : 1) // hub typically has 4 ports

#define CFG_TUH_HID                  4
#define CFG_TUH_HID_EPIN_BUFSIZE    64
#define CFG_TUH_HID_EPOUT_BUFSIZE   64

#ifdef __cplusplus
 }
#endif

#endif /* _TUSB_CONFIG_H_ */

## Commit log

2023-05-13 rev 0.1
    [babelfish-B_Cu.gbl, babelfish-B_Mask.gbs, babelfish-B_Paste.gbp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]
2023-05-26 rev2, pre review
    [babelfish.kicad_pcb, babelfish.kicad_sch]
2023-05-30 notes and pico debugging
2023-08-20 remove pico-pio-usb
2023-08-21 Abstract away UART
2023-08-22 don't use tinyusb bsp, fix event processing
    [host_adb.c, host_apollo.c, host_sun_keyboard.c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]
2023-08-26 remove bsp/board.h and fixes
    [babelfish_test.c, dbg_print.c, debug.c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]
2023-08-27 stdio uart, hid_app, bootmode processing, debugging
2023-09-30 Moved files aroud. WIP new power section
    [babelfish-B_Cu.gbl, babelfish-B_Mask.gbs, babelfish-B_Paste.gbp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]
2023-09-30 Power section done
    [babelfish.kicad_sch]
2023-10-01 Added muxes
    [babelfish.kicad_pcb, babelfish.kicad_sch]
2023-10-01 Layout v2 done
    [babelfish.kicad_pcb, babelfish.kicad_sch]
2023-10-02 V2 export WIP
    [babelfish-B_Cu.gbl, babelfish-B_Mask.gbs, babelfish-B_Paste.gbp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]
2023-10-07 Er, forgot to wire CH_B_S0/1
    [babelfish.kicad_pcb, babelfish.kicad_sch, babelfish.sch]
2023-10-13 enable usb aux power
2023-10-15 hw: Add back test points to schematic, fix db9 GND
    [babelfish.kicad_pcb, babelfish.kicad_sch]
2023-11-03 hw v0.3
    [babelfish.kicad_pcb, babelfish.kicad_sch]
2023-11-05 WIP fixing the mux/demux
    [babelfish.kicad_sch]
2023-11-06 more dip switch replacements
    [babelfish.kicad_sch]
2023-11-07 Move 5V power to TPS62933, from WEBENCH
    [babelfish.kicad_sch]
2023-11-07 WIP new power
    [babelfish.kicad_pcb, babelfish.kicad_sch]
2023-11-11 WIP -- pre-shift-up
    [babelfish.kicad_pcb, babelfish.kicad_sch]
2023-11-11 WIP dip switches
    [babelfish.kicad_pcb, babelfish.kicad_sch]
2023-11-18 Finished complex DC-DC layout, pre-deletion
    [babelfish.kicad_pcb]
2024-03-31 v3 rc0
    [babelfish.kicad_pcb, babelfish.kicad_sch]
2024-03-31 v3 rc2
    [babelfish.kicad_pcb]
2024-03-31 v3 production
    [babelfish-CuBottom.gbr, babelfish-CuIn1.gbr, babelfish-CuIn2.gbr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]
2024-05-12 Fix adb isr type
    [host_adb.c]
2024-05-13 Add B reboot, tweak protocol/report mode
    [debug.c]
2024-05-25 proper invert setup for apollo
    [host_apollo.c]
2024-05-27 Apollo works, after mouse fix
    [host_apollo.c]
2024-08-15 Fixes for pico-sdk 2.0
2025-09-16 Add schematic pdf
